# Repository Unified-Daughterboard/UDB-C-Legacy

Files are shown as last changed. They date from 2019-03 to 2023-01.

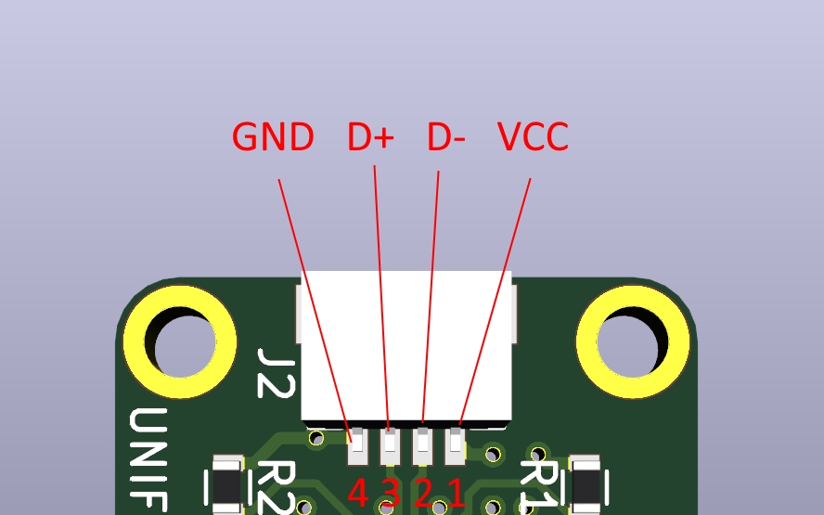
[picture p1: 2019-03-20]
Design Resources/C3/Pinout-JST-4.jpg

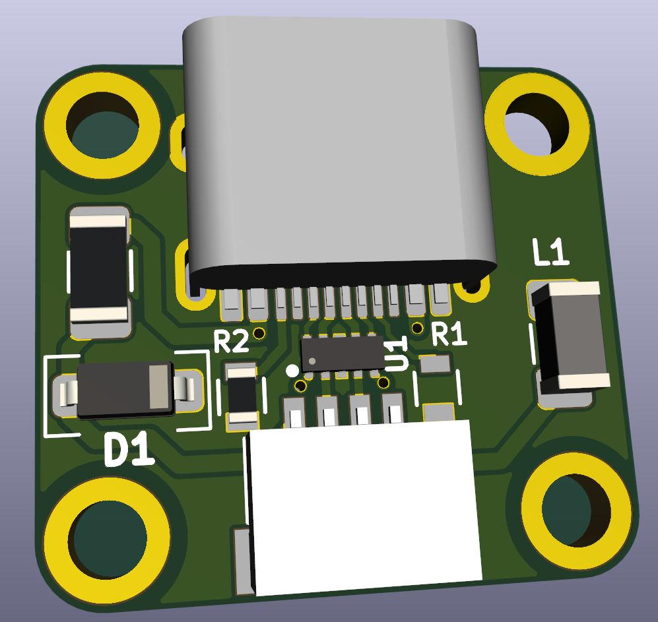
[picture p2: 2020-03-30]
Images/Daughterboard-C3-Top.png

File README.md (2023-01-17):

# Unified Daughterboard Legacy C Series

# Notice
The **C3 series daughterboard has been deprecated** with the launch of the [C4 series](https://github.com/Unified-Daughterboard/UDB-C).  
This repository will be kept up for the sake of the ability to maintain legacy keyboards, but the legacy C3 daughterboard is now not-for-new-designs - **please use the newer daughterboards instead for new keyboard projects**.  
  
In addition, documentation has moved to the new [documentation site](https://unified-daughterboard.github.io/).  

---

## Original Readme

<p align="center">
  
</p>
<p align="center">
  
</p>

## Introduction
The Unified Daughterboard Project is an attempt by leading designers in the mechanical keyboard community to standardize the USB daughterboards used for their custom mechanical keyboard projects. It has initially been envisioned by users ai03, Wilba, Hineybush, Xelus, Xondat, aeryxz and Maximillian.

The main characteristic of this daughterboard is to integrate a USB Type C connector and the needed circuitry for USB2.0 operation in a small PCB that can be screwed to a keyboard chassis; this significantly simplifies the assembly and design of the main circuit board.

## C3 version

In its current version, C3, this daughterboard features:

* ESD (Electrostatic Discharge) protection on the data lines of the USB connector through a specialized chip;
* Overcurrent protection through a PTC fuse;
* Overvoltage protection through a bidirectional TVS diode;
* Shielding noise decoupling capabilities through a ferrite bead;
* Single-path grounding of the metallic chassis to which the daughterboard is attached.

Adittionally, the C3 version is backwards compatible with both C1 and C2 versions since it has the same dimensions and uses the same screw hole sizes and positions, so keyboards designed using the past versions should also support C3.

## Detailed features

The figure below shows the schematic of the C3 version.

<p align="center">
  
</p>

* U1 is the ESD protection for the USB data lines. It is a ultra-fast, low-capacitance chip specifically designed for USB type C connectors. When one of the data lines presents a sudden voltage spike, this chip promptly grounds it -- avoiding damage to the circuit that uses these lines;
* Resistors R1 and R2 are the CC resistors needed for operation of the USB Type C. These resistors are used by the USB host to know that the daughterboard is a downstream device and which side of the USBC connector is connected;
* Fuse F1 provides overcurrent protection. It is a PTC resettable;
* Diode D1 is a Transient Voltage Suppressor that exerpts to the power rails of the connector the same effect as the U1 chiup to data lines; when a voltge spike is detected, it shorts VCC and GND, aavoiding damage to the forward circuitry;
* Inductor L1 is a ferrite bead that presetns a very low impedance between the power ground and the signal ground in DC regimen; in high frequencies (for instance in an ESD event) it presents a very high impedance, avoiding noisy currents passing to the signal GND;
* The daughterboard features four screw holes used to fix it into a metal chassis. The top left mounting hole is shorted to the power ground signal; this means that the metal chassis of the keyboard will be grounded. However, the other three screw holes are not shorted to the power ground and are effectively isolated from that signal. This ensures that, in a discharge event emerging from the user providing charge to the system, the discharge current will have a single path through the daughterboard to the power ground; inductor L1 ensures that the discharge current is kept in the power ground plance and does not follow through to the signal ground.

## Designer/Consumer info and references
[Visit the docs](https://unified-daughterboard.github.io/)  

## Previews
Render
Render

## Credits
* [Gondolindrim](http://github.com/Gondolindrim)
* [ai03](http://github.com/ai03-2725)
* [Wilba](https://github.com/Wilba6582)
* [Hineybush](http://github.com/hineybush)
* [Xelus](http://github.com/Xelus22)
* Xondat
* [aeryxz](https://github.com/aeryxz)
* [Maximillian](https://github.com/Maximillian)
* [Upas](http://github.com/awkannan)

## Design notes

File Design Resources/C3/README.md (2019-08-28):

# Info for designers

* The production data is in the Production folder, including a prepared Elecrow production dataset.
* The pinout is as shown in Pinout-JST-4.jpg. The same pinout is to be followed on the mainboard side.
* The cable used to connect the daughterboard and mainboard must be a one-to-one cable.
* A 3D model is provided in step format. This can be imported into CAD programs for accurate modelling. 
* The screws used to secure the daughterboard are M2 spec.

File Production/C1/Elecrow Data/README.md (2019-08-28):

# Elecrow Production Data
The zipped files in this directory contain all of the necessary files for PCB assembly at Elecrow.  
The included spec file is for 20 quantity in black. Please edit Unified-Daughterboard-Elecrow.xlsx and re-zip to change color and quantity options.

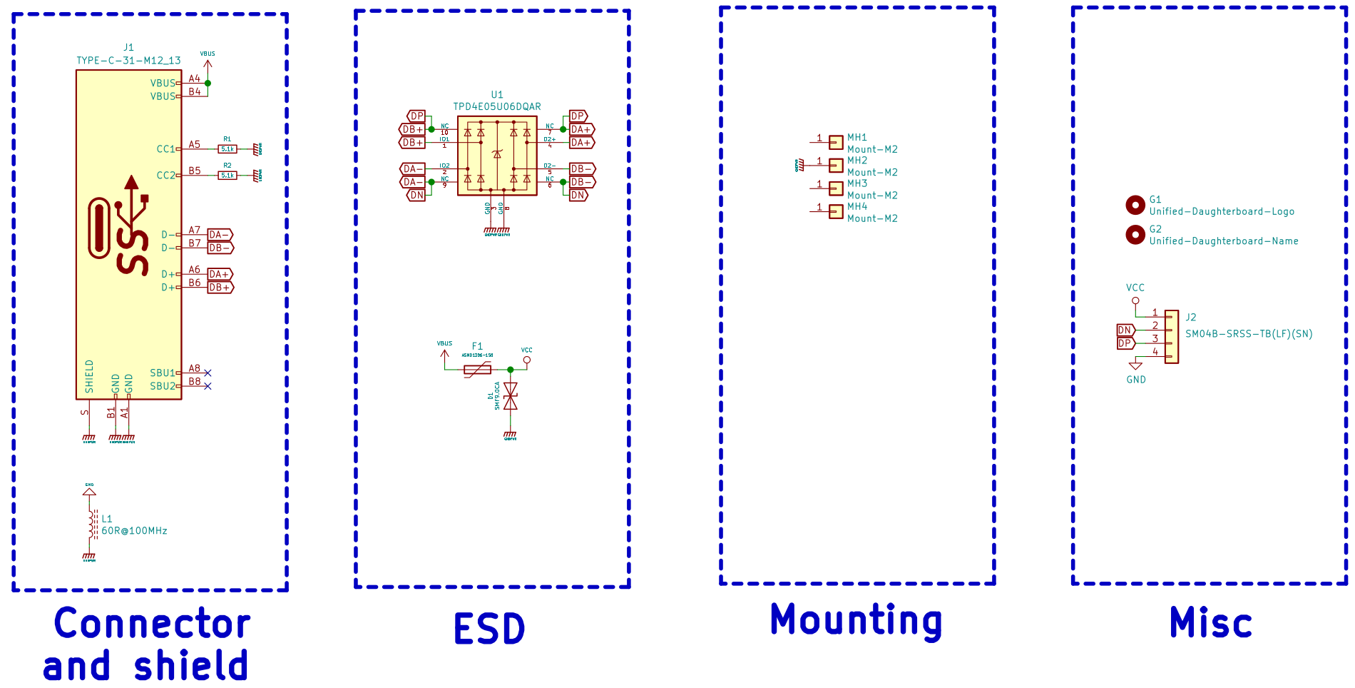
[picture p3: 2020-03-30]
Images/C3-schematic.png

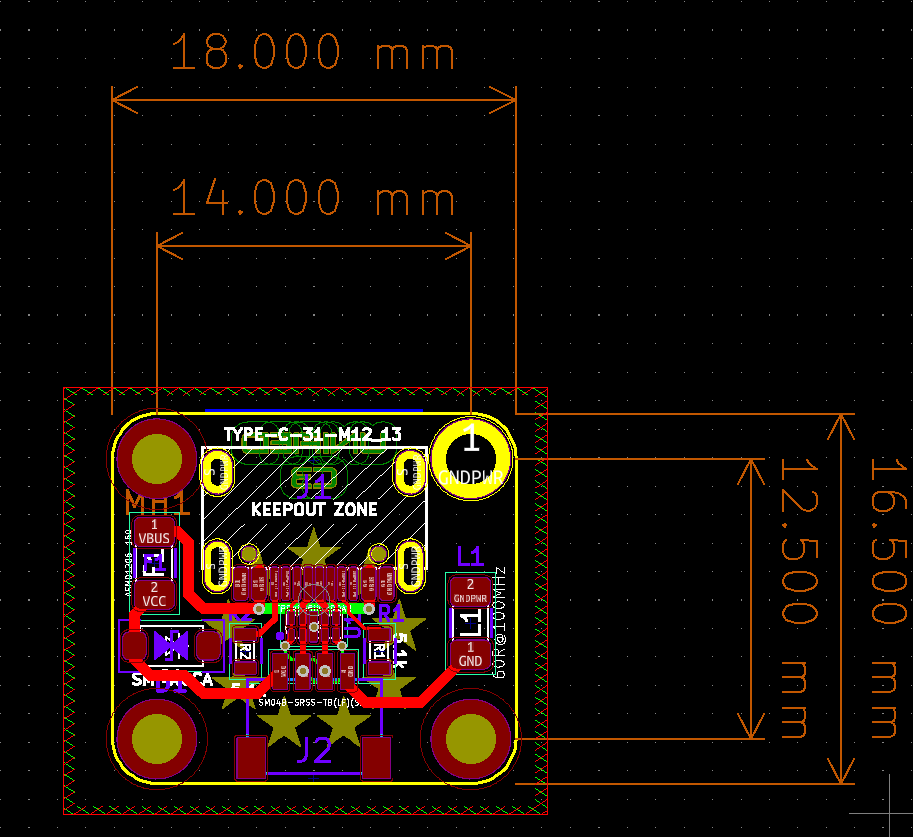
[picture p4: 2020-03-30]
Design Resources/C3/C3-Dimens.png

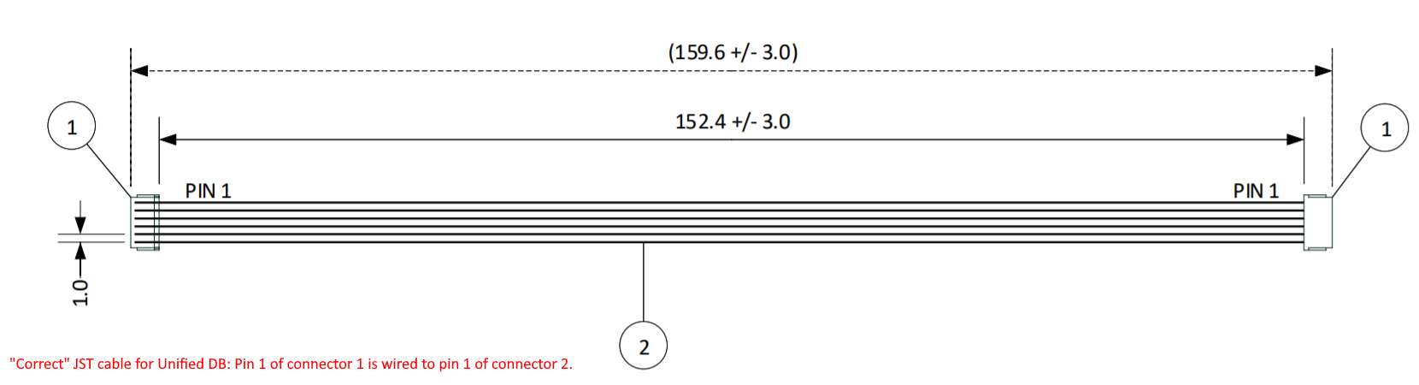
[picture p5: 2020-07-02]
Images/jst-correct.png

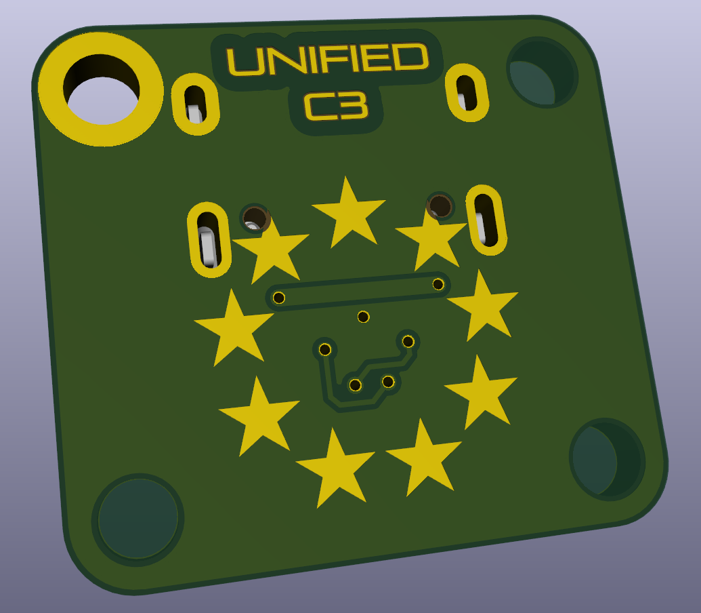
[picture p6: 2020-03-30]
Images/Daughterboard-C3-Bottom.png

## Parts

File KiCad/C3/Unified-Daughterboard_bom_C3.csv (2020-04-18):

Component | Description | Part | References | Value | Footprint | Quantity Per PCB | Datasheet | Package | LCSC Part No | Manufacturer Part No | Manufacturer
1 | Bidirectional transient-voltage-suppression diode | D_TVS | D1 | SMF9.0CA | D_SOD-123_Bidirectional | 1 | ~ | SOD-123F-B | C123799 | SMF9.0CA | Microdiode Electronics
2 | Resettable fuse, polymeric positive temperature coefficient | Polyfuse | F1 | ASMD1206-150 | Fuse_1206_3216Metric | 1 | ~ | F1206 | C135342 | ASMD1206-150 | Shenzhen JDT Fuse
3 | Generic connector, single row, 01x04, script generated (kicad-library-utils/schlib/autogen/connector/) | Conn_01x04 | J2 | SM04B-SRSS-TB(LF)(SN) | JST-SR-4 | 1 | ~ |  | C160404 | SM04B-SRSS-TB(LF)(SN) | JST Sales America
4 |  | TYPE-C-31-M12_13 | J1 | TYPE-C-31-M12_13 | TYPE-C-31-M-12 | 1 |  |  | C165948 | TYPE-C-31-M-12 | Korean Hroparts
5 | Inductor with ferrite core | L_Core_Ferrite | L1 | 60R@100MHz | L_1206_3216Metric | 1 | ~ | L1206 | C33600 | MLB3216-600P4A(f) | MELED Industrial
6 | Resistor, small symbol | R_Small | R1 R2 | 5.1k | R_0603 | 2 | ~ | R0603
7 |  | TPD4E05U06DQAR | U1 | TPD4E05U06DQAR | USON-10_2.5x1.0mm_P0.5mm | 1 |  | uSON-10 | C138714 | TPD4E05U06DQAR | Texas Instruments
Component Groups: | 7
Component Count: | 8
Fitted Components: | 8
Number of PCBs: | 1
Total components: | 8
Schematic Version: | C3
Schematic Date: | 2020-03-22
BoM Date: | 4/18/2020 9:20:34 PM
Schematic Source: | C:\Users\Ryota Goto\Documents\GitHub\Unified-Daughterboard\KiCad\C3\Unified-Daughterboard.sch
KiCad Version: | Eeschema (5.1.4)-1

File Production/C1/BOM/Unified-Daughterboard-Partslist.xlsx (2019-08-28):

Component | Description |  | Part | References | Value | Footprint | Quantity Per PCB
1 | JST SR | https://lcsc.com/product-detail/Others_JST-Sales-America__JST-Sales-America-SM04B-SRSS-TB-LF-SN_C160404.html | Conn_01x04 | J2 | SM04B-SRSS-TB(LF)(SN) | JST-SR-4 | 1
2 | HRO USB-C Connector | https://lcsc.com/product-detail/USB-Type-C_Korean-Hroparts-Elec-TYPE-C-31-M-12_C165948.html | HRO-TYPE-C-31-M-12 | J1 | HRO-TYPE-C-31-M-12 | HRO-TYPE-C-31-M-12-Assembly | 1
3 | Resistor, 0603, Generic | https://lcsc.com/product-detail/Chip-Resistor-Surface-Mount_PANASONIC-ERA3AED512V_C191166.html | R_Small | R1 R2 | 5.1k | R_0603 | 2

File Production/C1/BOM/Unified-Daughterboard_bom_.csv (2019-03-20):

Component | Description | Part | References | Value | Footprint | Quantity Per PCB | Datasheet
1 | JST Connector, SR series, 4 pin, 1mm pitch - SM04B-SRSS-TB(LF)(SN) | Conn_01x04 | J2 | SM04B-SRSS-TB(LF)(SN) | JST-SR-4 | 1 | ~
2 | USB Type-C Connector HRO TYPE-C-31-M-12 | HRO-TYPE-C-31-M-12 | J1 | HRO-TYPE-C-31-M-12 | HRO-TYPE-C-31-M-12-Assembly | 1
3 | Resistor, small symbol | R_Small | R1 R2 | 5.1k | R_0603 | 2 | ~
Component Groups: | 3
Component Count: | 4
Fitted Components: | 4
Number of PCBs: | 1
Total components: | 4
Schematic Version:
Schematic Date:
BoM Date: | 3/19/2019 21:51
Schematic Source:
KiCad Version: | Eeschema (5.0.2)-1

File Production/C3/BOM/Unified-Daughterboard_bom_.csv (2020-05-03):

Designator | Package | Quantity | Designation | LCSC Code
D1 | SOD-123F-B | 1 | SMF9.0CA | C123799
J2 | SM04B-SRSS-TB(LF)(SN) | 1 | JST-SM04B | C160404
R1,R2 | R0603 | 2 | 5.1k | C101083
J1 | HRO-TYPE-C-31-M-12 | 1 | HRO-TYPE-C-31-M-12 | C165948
U1 | uSON-10 | 1 | TPD4E05U06DQAR | C138714
F1 | F1206 | 1 | ASMD1206-150 | C135342

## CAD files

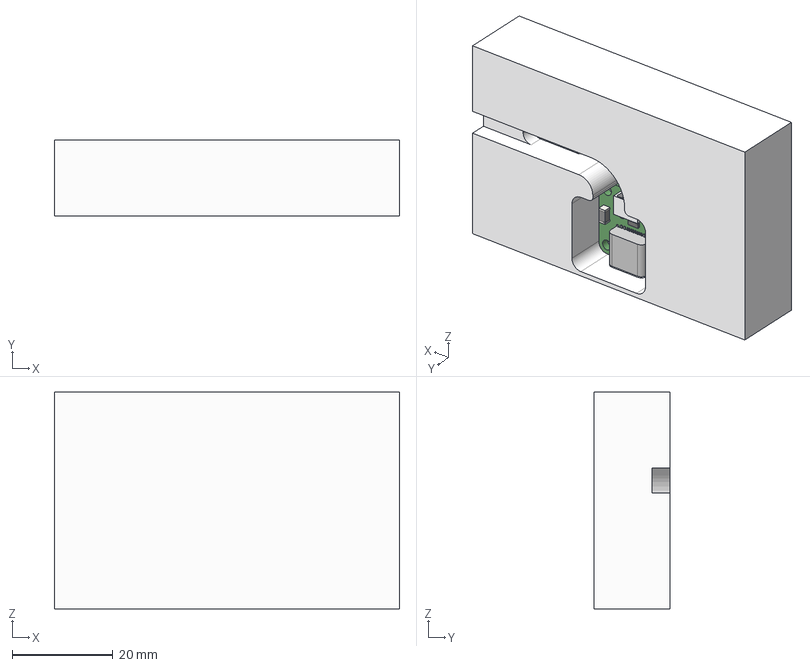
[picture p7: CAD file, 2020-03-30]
Design Resources/C3/Example Implementation Model.step
68.5 x 15.0 x 43.0 mm

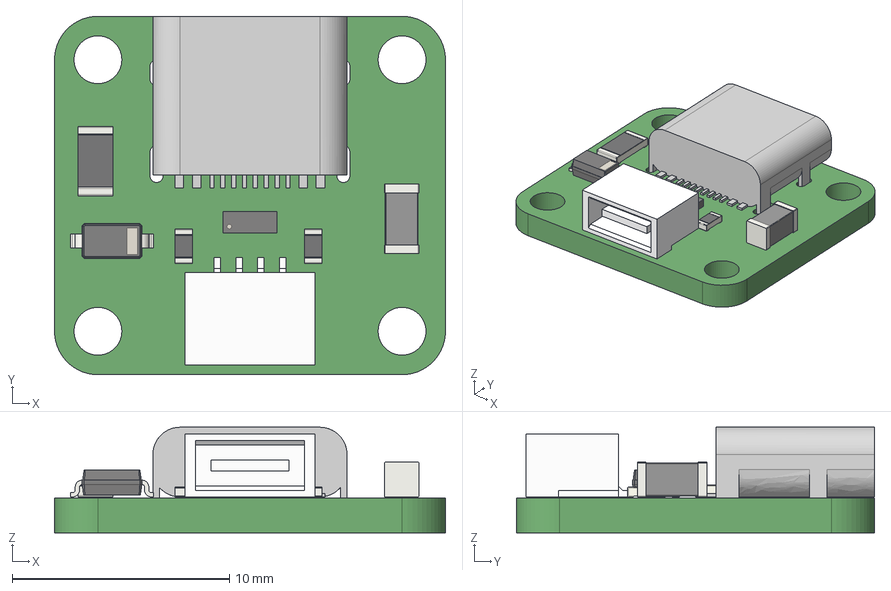
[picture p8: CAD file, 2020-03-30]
Design Resources/C3/Unified-Daughterboard.step
18.0 x 16.5 x 4.86 mm

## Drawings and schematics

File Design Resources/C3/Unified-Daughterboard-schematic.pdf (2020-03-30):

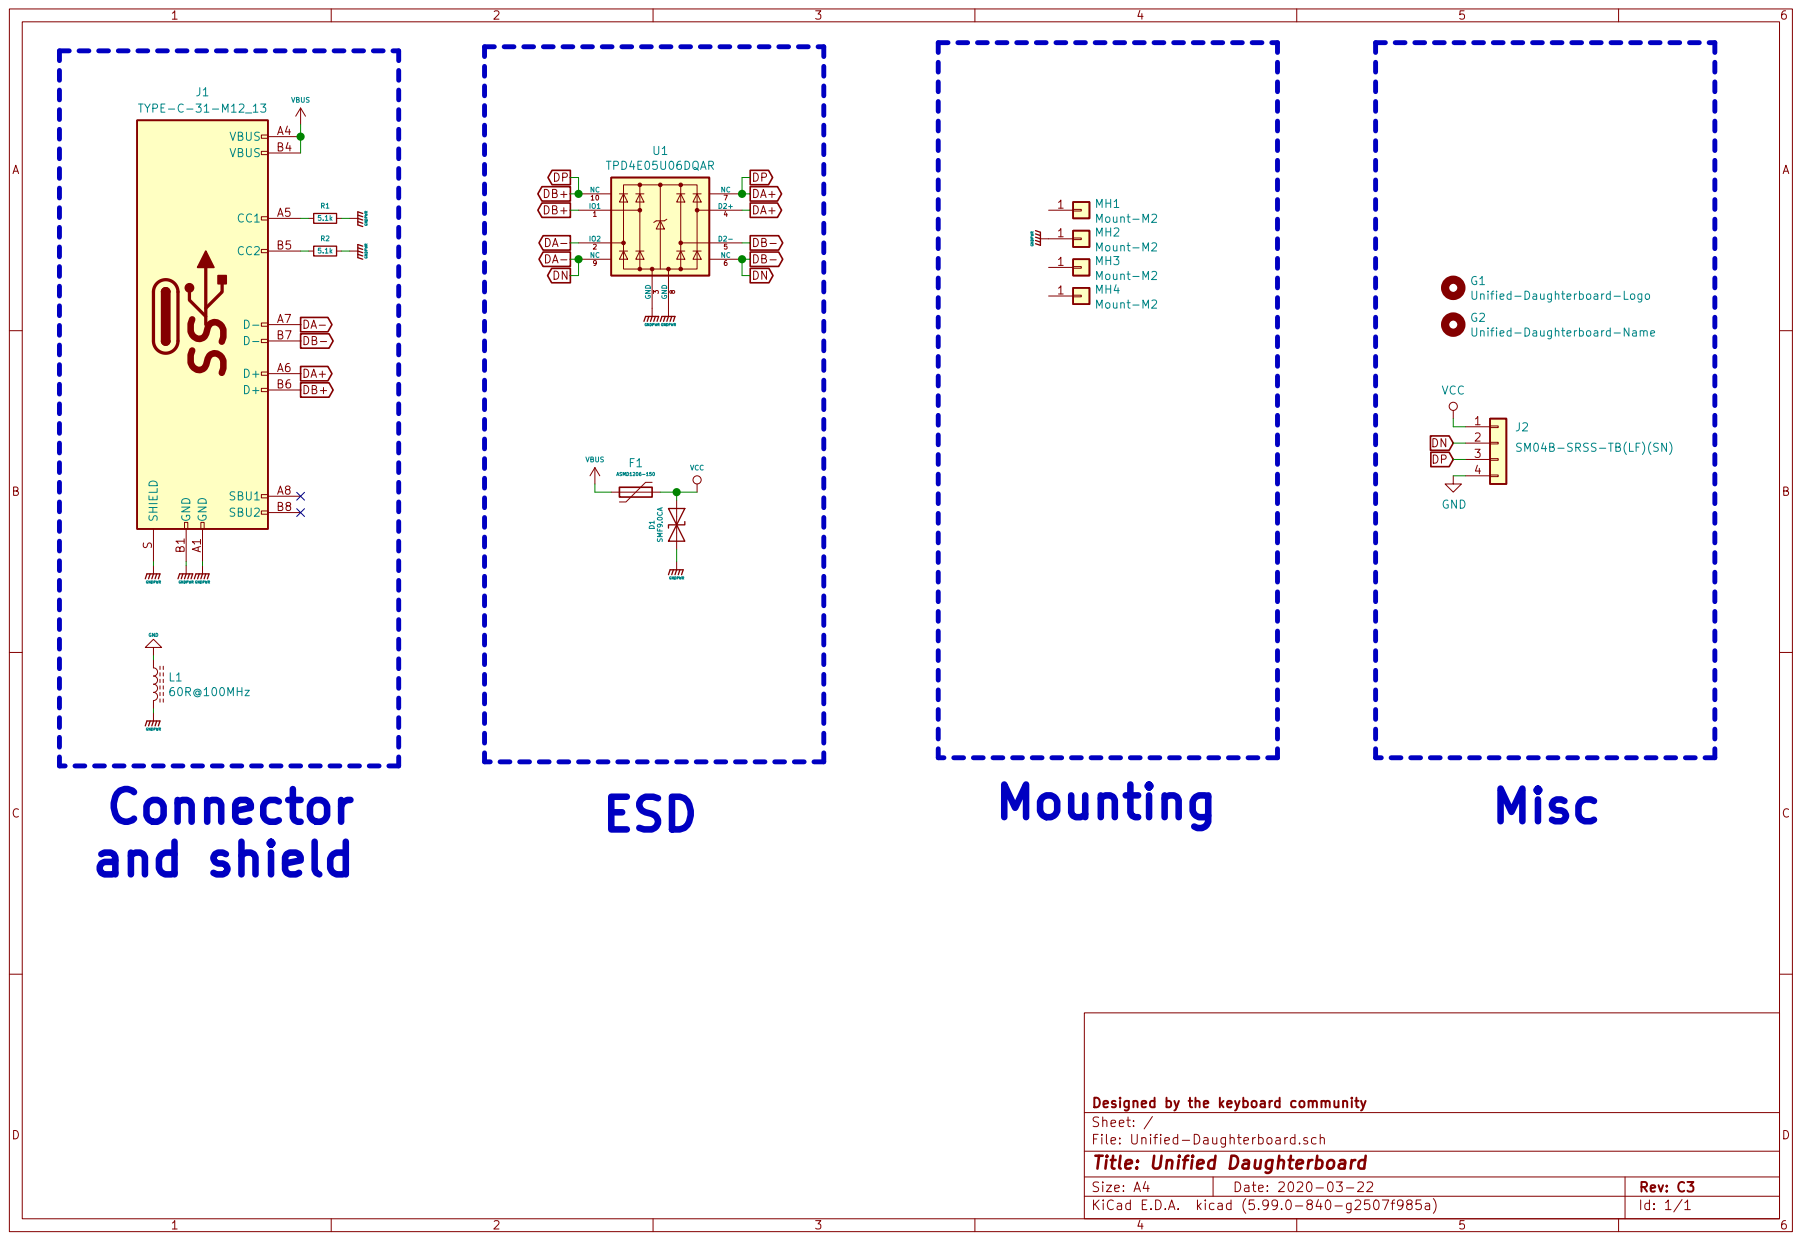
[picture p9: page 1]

J2SM04B-SRSS-TB(LF)(SN) GNDPWR

File: Unified-Daughterboard.sch Sheet: / Designed by the keyboard community

Id: 1/1 Title: Unified Daughterboard

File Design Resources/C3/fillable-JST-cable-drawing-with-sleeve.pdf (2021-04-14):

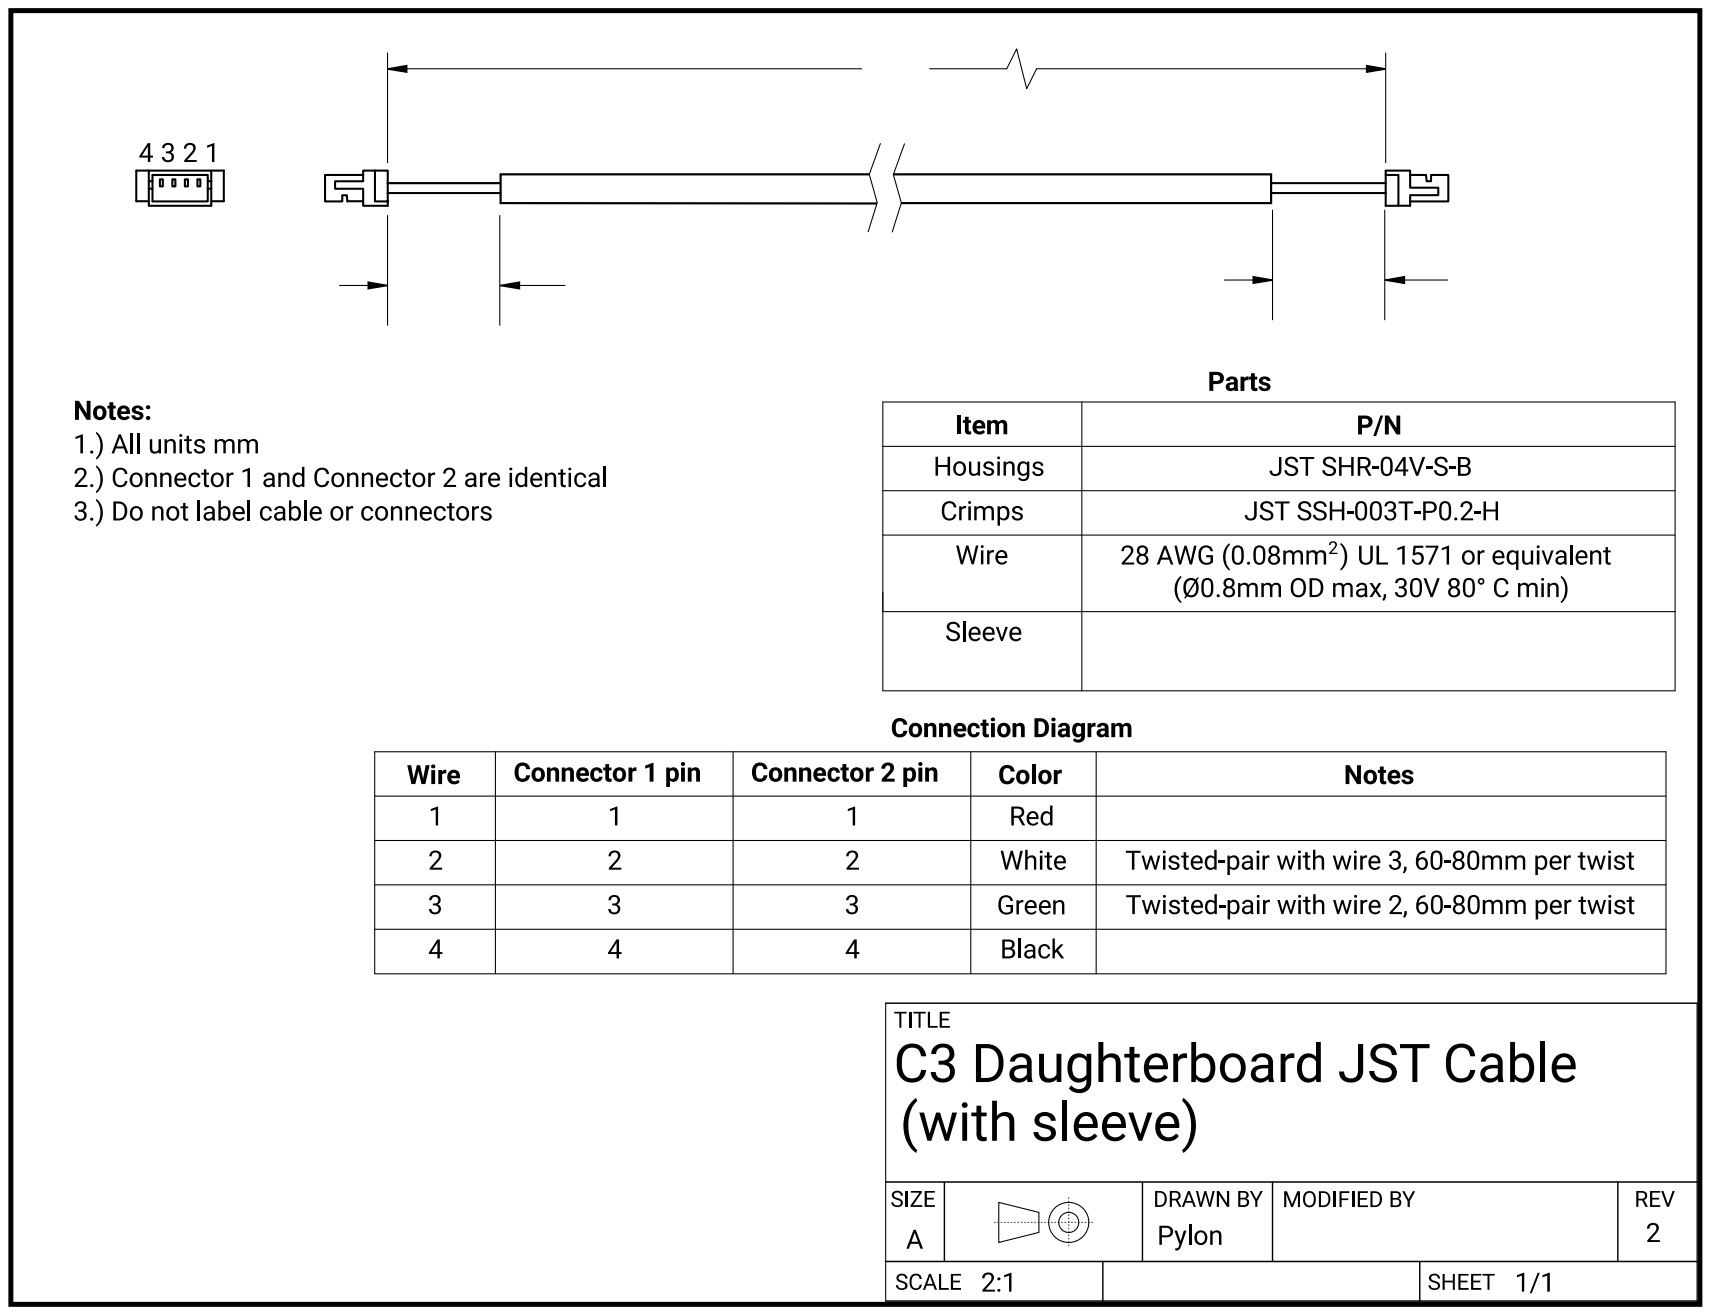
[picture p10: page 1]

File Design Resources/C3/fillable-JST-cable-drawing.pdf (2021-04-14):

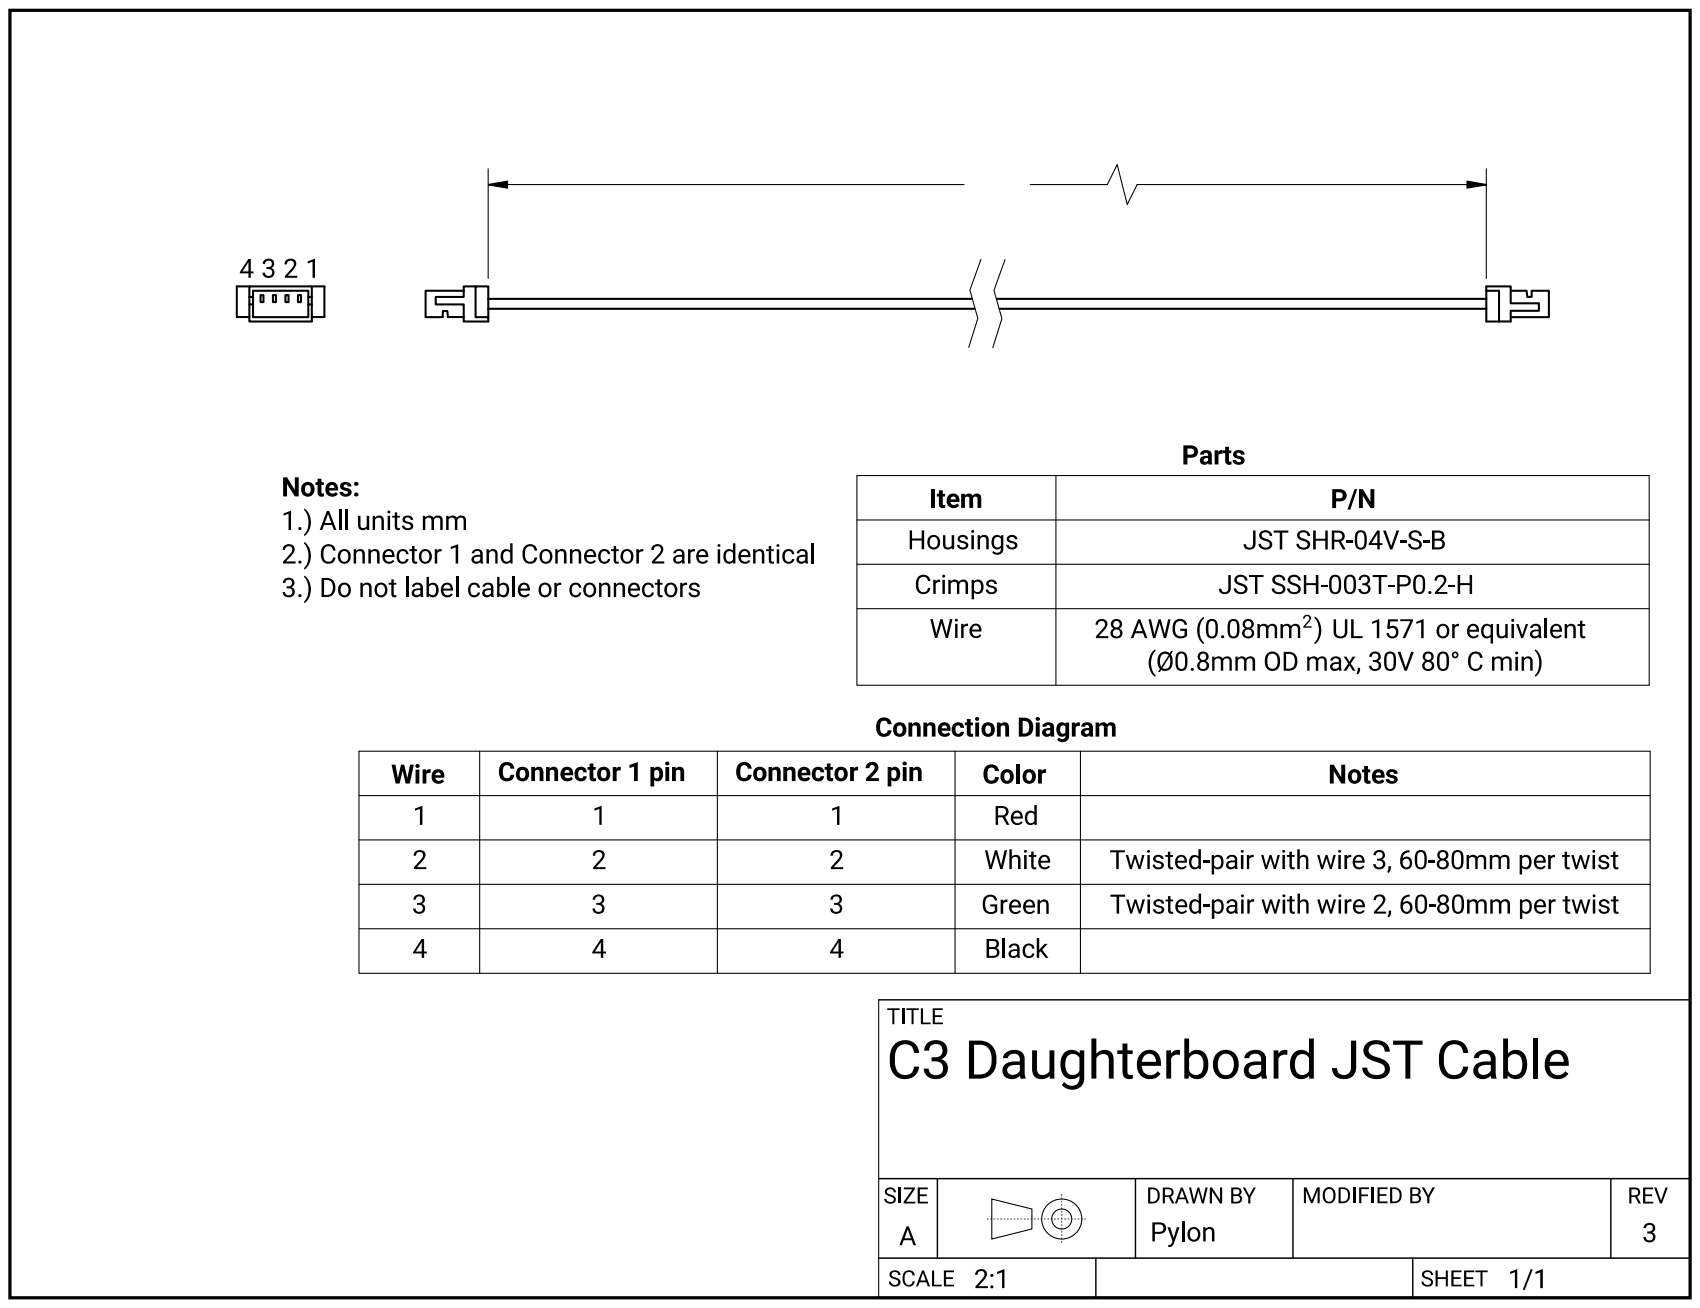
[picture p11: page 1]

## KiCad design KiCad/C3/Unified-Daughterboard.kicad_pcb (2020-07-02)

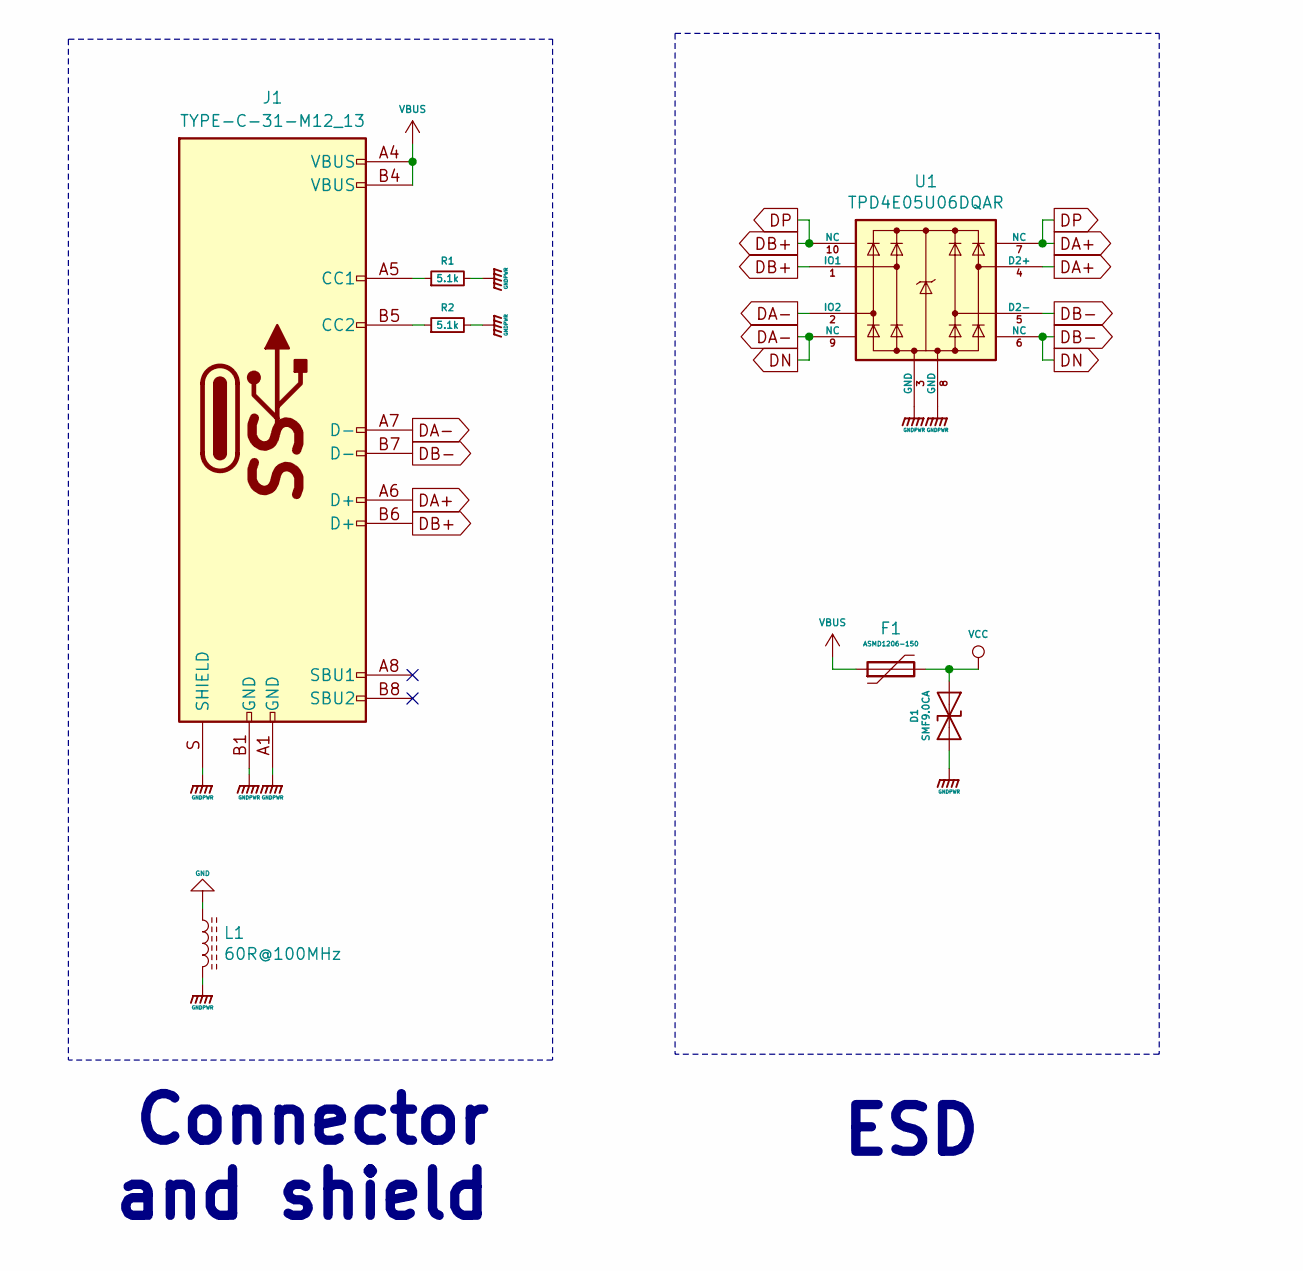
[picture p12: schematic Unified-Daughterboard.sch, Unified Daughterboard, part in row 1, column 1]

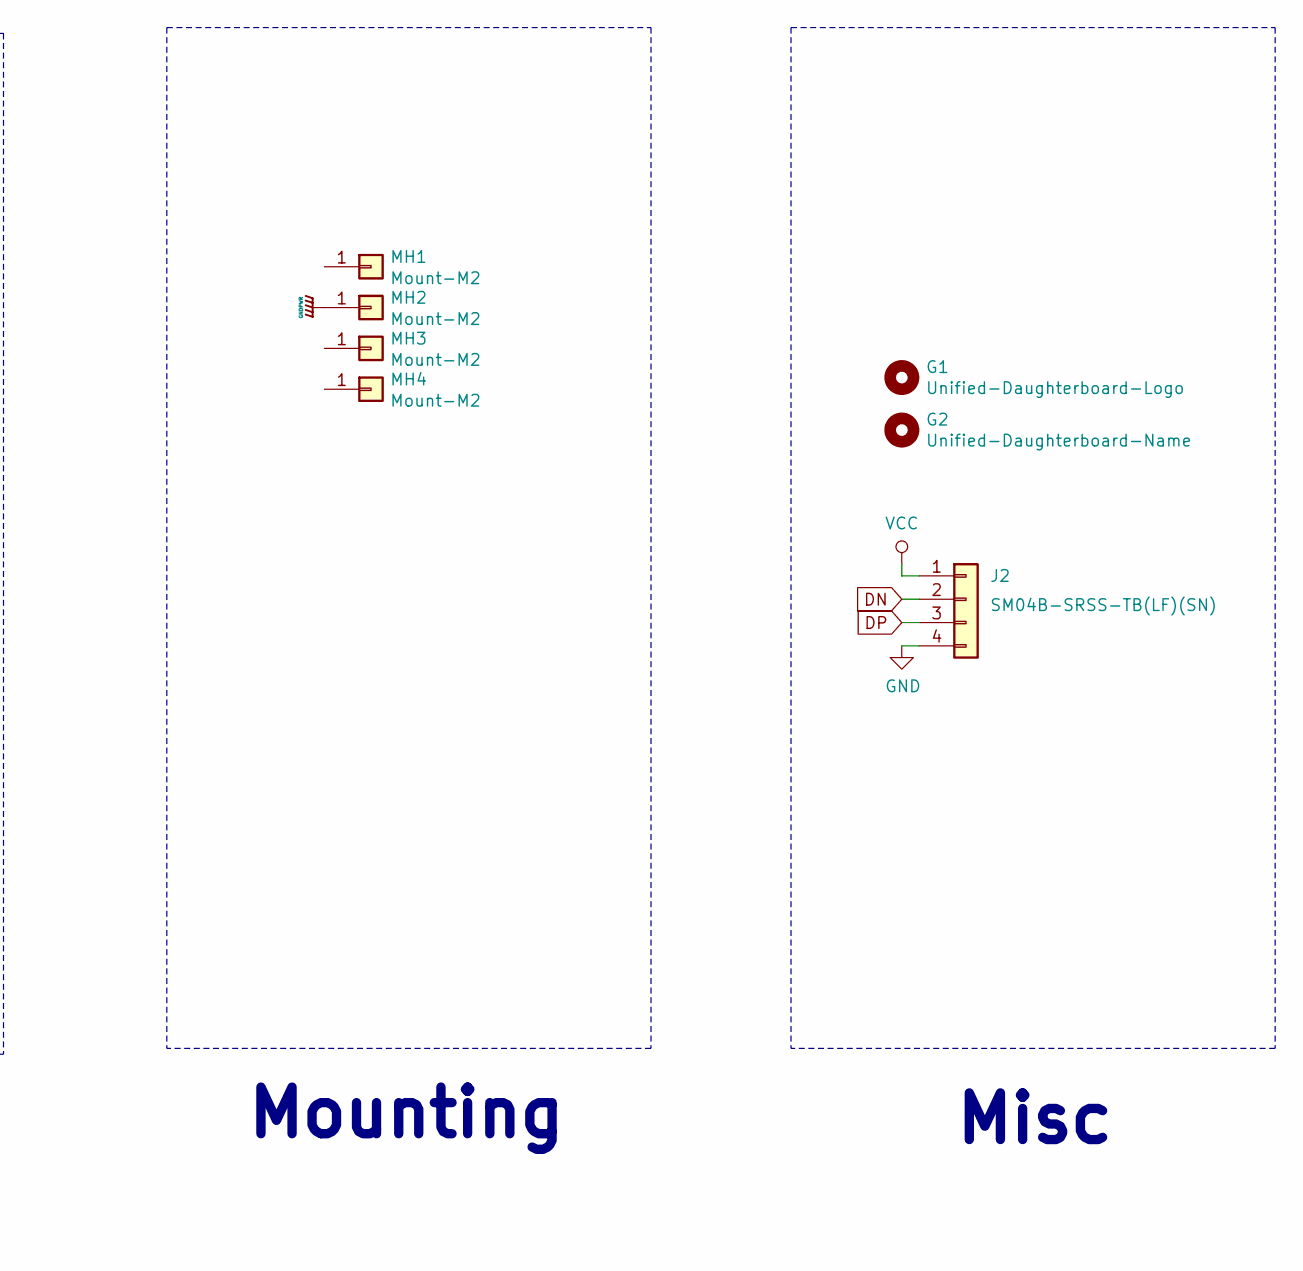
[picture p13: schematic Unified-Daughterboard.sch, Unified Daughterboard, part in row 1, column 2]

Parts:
D1: SMF9.0CA; D_SOD-123_Bidirectional; Manufacturer Part No SMF9.0CA; LCSC Part No C123799
F1: ASMD1206-150; Fuse_1206_3216Metric; Manufacturer Part No ASMD1206-150; LCSC Part No C135342
G1: Unified-Daughterboard-Logo; Unified-Daughterboard-Logo.pretty
G2: Unified-Daughterboard-Name; Unified-Daughterboard-Name.pretty
J1: TYPE-C-31-M12_13; TYPE-C-31-M-12; Manufacturer Part No TYPE-C-31-M-12; LCSC Part No C165948
J2: SM04B-SRSS-TB(LF)(SN); JST-SR-4; Manufacturer Part No SM04B-SRSS-TB(LF)(SN); LCSC Part No C160404
L1: 60R@100MHz; L_1206_3216Metric; Manufacturer Part No MLB3216-600P4A(f); LCSC Part No C33600
MH1, MH2, MH3, MH4: Mount-M2; Generic-Mounthole
R1, R2: 5.1k; R_0603
U1: TPD4E05U06DQAR; USON-10_2.5x1.0mm_P0.5mm; Manufacturer Part No TPD4E05U06DQAR; LCSC Part No C138714

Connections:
DA+: J1.A6 (D+), J1.B6 (D+), J2.3, U1.1 (IO1), U1.4 (D2+), U1.7 (NC), U1.10 (NC)
DA-: J1.A7 (D-), J1.B7 (D-), J2.2, U1.2 (IO2), U1.5 (D2-), U1.6 (NC), U1.9 (NC)
GND: J2.4, L1.1
GNDPWR: D1.1 (A1), J1.A1 (GND), J1.B1 (GND), J1.S (SHIELD), L1.2, MH2.1, R1.2, R2.2, U1.3 (GND), U1.8 (GND)
unnamed: J1.A5 (CC1), R1.1
unnamed: J1.B5 (CC2), R2.1
VBUS: F1.1, J1.A4 (VBUS), J1.B4 (VBUS)
VCC: D1.2 (A2), F1.2, J2.1

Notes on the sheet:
Connector and shield
ESD
Mounting
Misc

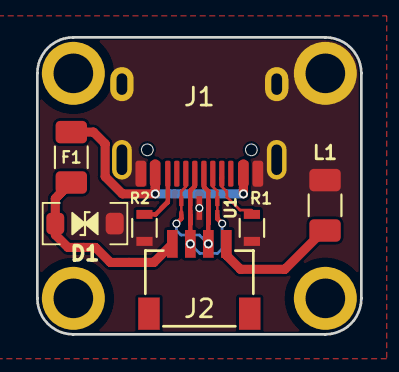
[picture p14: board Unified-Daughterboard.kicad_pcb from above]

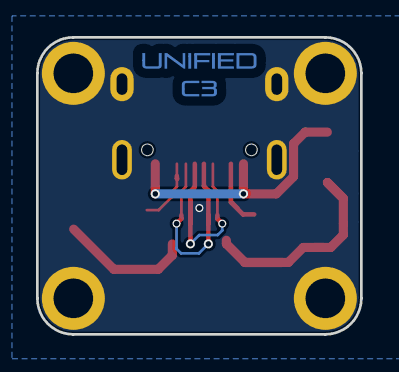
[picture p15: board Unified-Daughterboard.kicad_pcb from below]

Board: 2 copper layers, 18.0 x 16.5 mm, 14 parts (2 on the bottom side), 8 nets.

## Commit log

2019-03-20 Build the daughterboard
    [Unified-Daughterboard.kicad_pcb, Unified-Daughterboard.sch, Unified-Daughterboard.step]
2019-03-20 Generate production files
    [Unified-Daughterboard-B.Cu.gbl, Unified-Daughterboard-B.Mask.gbs, Unified-Daughterboard-B.Paste.gbp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]
2019-03-20 Add designer resources
    [Unified-Daughterboard.step]
2019-03-20 Begin move files
    [Unified-Daughterboard-B.Cu.gbl, Unified-Daughterboard-B.Mask.gbs, Unified-Daughterboard-B.Paste.gbp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]
2019-08-28 Update with elecrow production data
    [Unified-Daughterboard-Elecrow.xlsx, Unified-Daughterboard-Partslist.xlsx, Unified-Daughterboard.kicad_pcb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]
2019-08-28 Add screw info
2020-01-08 Organized schematic
    [Unified-Daughterboard.sch]
2020-01-08 Improved grounding and shielding
    [Unified-Daughterboard.kicad_pcb, Unified-Daughterboard.sch]
2020-01-08 Move from C1 folder to C2
    [Unified-Daughterboard.kicad_pcb, Unified-Daughterboard.sch]
2020-01-08 Add design resources and images for C2
    [Unified-Daughterboard-Elecrow.xlsx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]
2020-03-22 Initial proposed version
    [Unified-Daughterboard-Elecrow.xlsx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]
2020-03-23 Detailed schematic and features in README
2020-03-23 Fix schematic size in readme
2020-03-23 Solve star logo potential overflow
    [Unified-Daughterboard.kicad_pcb]
2020-03-30 Update 3D model
    [Unified-Daughterboard.step]
2020-03-30 Create Example Implementation Model.step
    [Example Implementation Model.step]
2020-03-30 Add zipped gerber and CSV position file
    [Unified-Daughterboard-top-pos.csv]
2020-04-08 Remove outdated files
    [Unified-Daughterboard-Elecrow.xlsx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]
2020-04-18 Remove C2 source to avoid confusion; repair C3 BOM
    [Unified-Daughterboard.kicad_pcb, Unified-Daughterboard.sch, Unified-Daughterboard_bom_.csv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]
2020-05-02 Remove capacitors from BoM and re-link separated pour
    [Unified-Daughterboard.kicad_pcb, Unified-Daughterboard.sch, Unified-Daughterboard_bom_.csv]
2020-05-03 Update gerber
    [Unified-Daughterboard-B_Cu.gbl, Unified-Daughterboard-B_Fab.gbr, Unified-Daughterboard-B_Mask.gbs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]
2020-06-26 Edit PCB file to be able to open in KiCAD 5.1.4
    [Unified-Daughterboard.kicad_pcb]
2020-07-02 Add cable reference
2020-07-02 Add cable images here as well
2020-07-02 Repair 3D model for resistor
    [Unified-Daughterboard.kicad_pcb]
2020-10-17 Added cable drawings with a fillable fields
